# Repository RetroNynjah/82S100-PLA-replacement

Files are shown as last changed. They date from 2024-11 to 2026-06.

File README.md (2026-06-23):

# 82S100 CPLD based PLA replacement
This replacement is a remix of [an old design by Mattis Lind](https://github.com/MattisLind/82S100replacement) based on the ATF1502 and compatible PLDs.  
Revision 1 of the board uses the same pinout so my board can be used with MattisLind's C64 PLA code without modification.
Revision 1b is reverted. The parts are on the back side giving the PLA a cleaner look. Because it's inverted, the pinout of the CPLD is different and it needs different code. Grab code for the right PCB!  

## Code
I have made minor adjustments to Mattis's code to enable the CE pin. The CE pin is grounded in all Commodore machines but this makes the PLA match the original better when tested in chip testers that test the CE pin.
The code is written in CUPL. PLD, JED and SVF files are available in the hdl folder for each board revision.
I have created PLA code for the below models
|Model |Part number |
|:--- |:---  |
|C64 |906114-01 |
|CBM-II HP |906114-05 |
|C16 & Plus/4  |251641-02 |
|CBM 1551 |251641-03 |

## Programming
The CPLD is programmed using JTAG. I'm writing the with svf files using OpenOCD and a FT232H USB breakout board.  
Just be sure to grab the right svf file for your pcb revision.

## Testing
I have custom logic device definitions for Xgpro for the Minipro TL866-II and T48. Those can be used to verify that you have written the correct file and that the PCB is soldered correctly.

## BOM
The part count is low: One ATF1502 CPLD, two 100nF caps (0603) and suitable pin headers.
For rev 1, I prefer flat pins (Arduino stackable headers) or SIL contact strips like [TE 1544210-2](https://www.digikey.se/short/f8hvfqzt) for a number of reason. They give a much lower profile, they stick better to sockets than round machined pins do and they are not as fragile as machined pins. The low profile is ideal for the Plus/4 and the 1551 paddle PLA.  
For rev 1b, machined pins are better as the components are mounted on the back side and the machined headers adds the necessary clearance.  

The CPLD I've been using and recommend is ATF1502ASL-25AU44. It's possible that other varations may work too but it needs to be a 5V part. The 10ns version is causing glitches when used for a C64 PLA.

## Rev 1
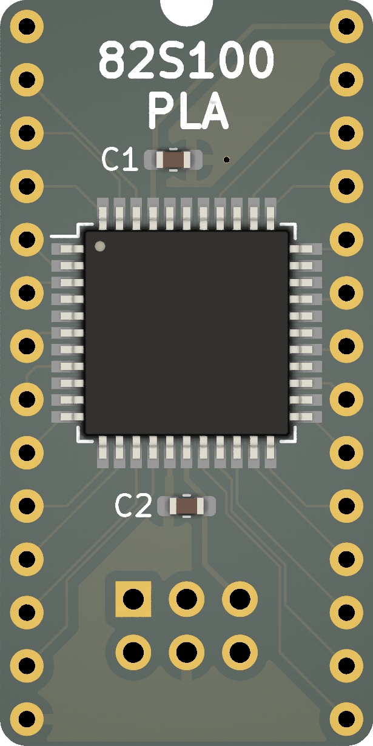
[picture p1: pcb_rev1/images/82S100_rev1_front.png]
Rev 1 front view
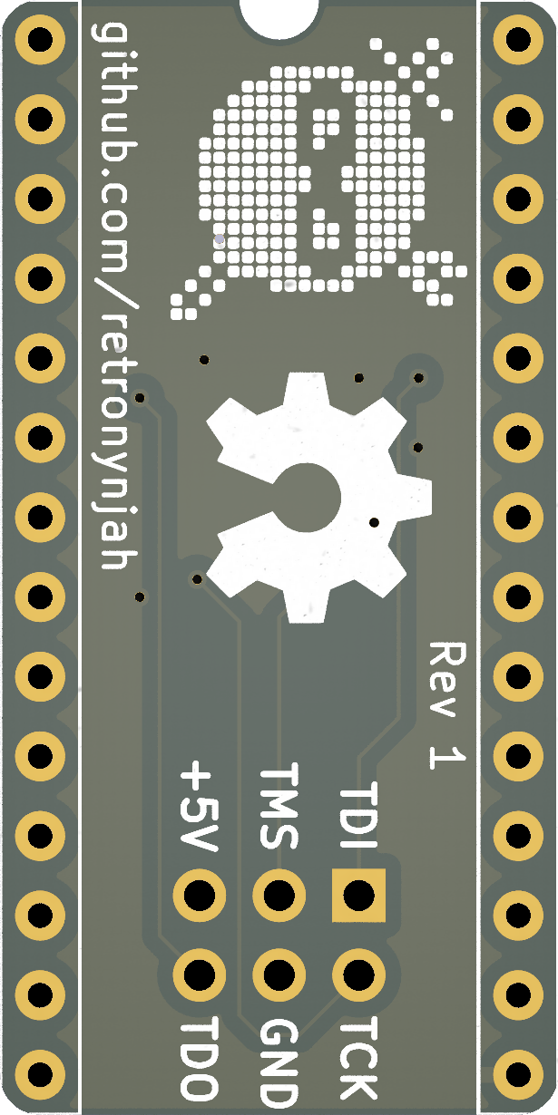
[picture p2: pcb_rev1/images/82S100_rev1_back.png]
Rev 1 back view
    
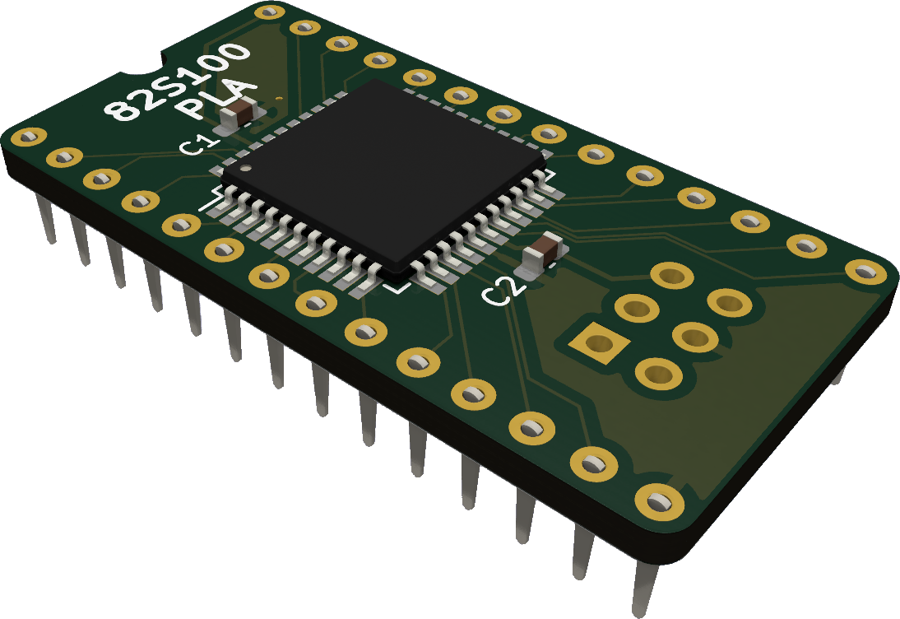
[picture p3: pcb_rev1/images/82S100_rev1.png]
Rev 1b rendered image
  
## Rev 1b
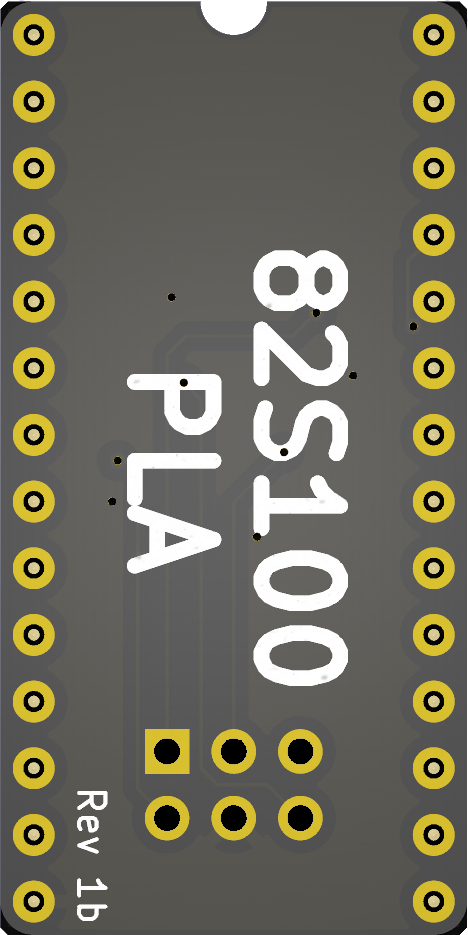
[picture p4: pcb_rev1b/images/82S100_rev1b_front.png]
Rev 1b front view
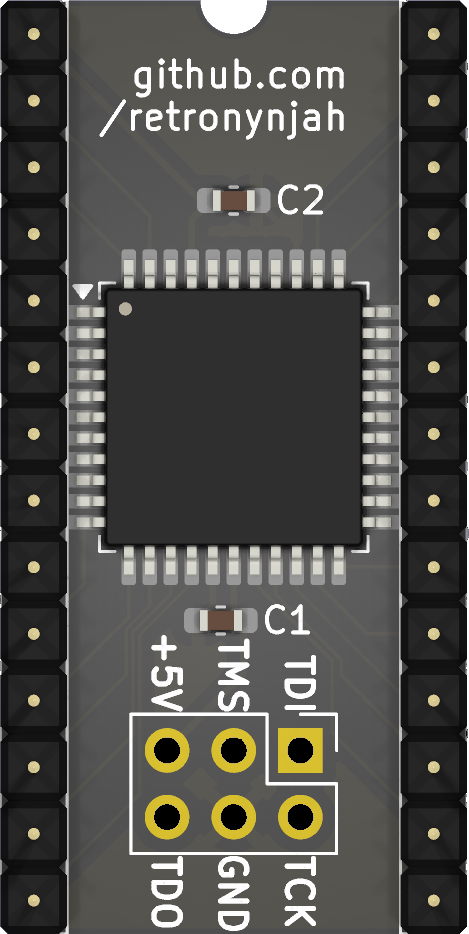
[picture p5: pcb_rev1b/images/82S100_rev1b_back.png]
Rev 1b back view
    
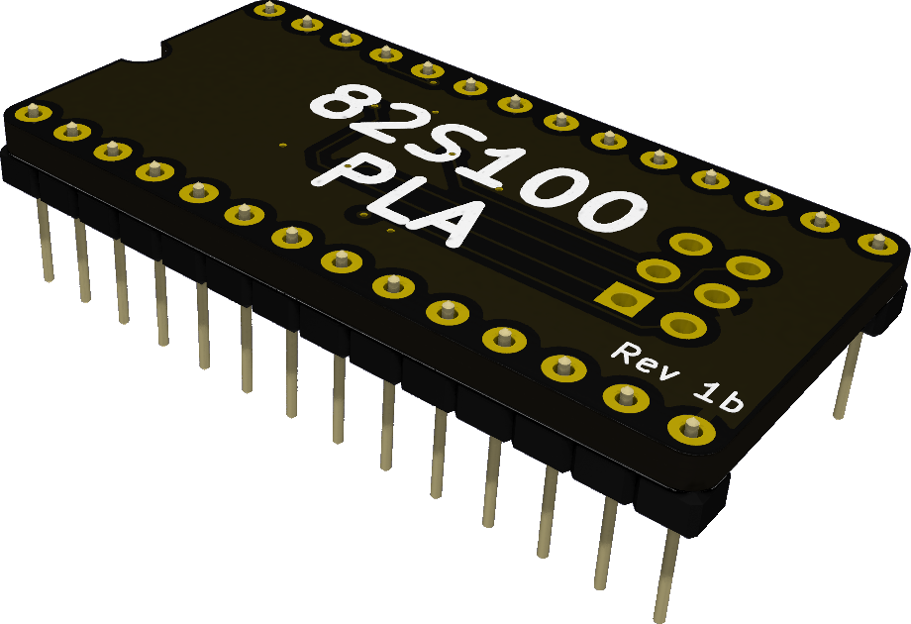
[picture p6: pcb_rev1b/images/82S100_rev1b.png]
Rev 1b rendered image


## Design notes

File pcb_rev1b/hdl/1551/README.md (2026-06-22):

## PLA replacement for Commodore 1551 paddle
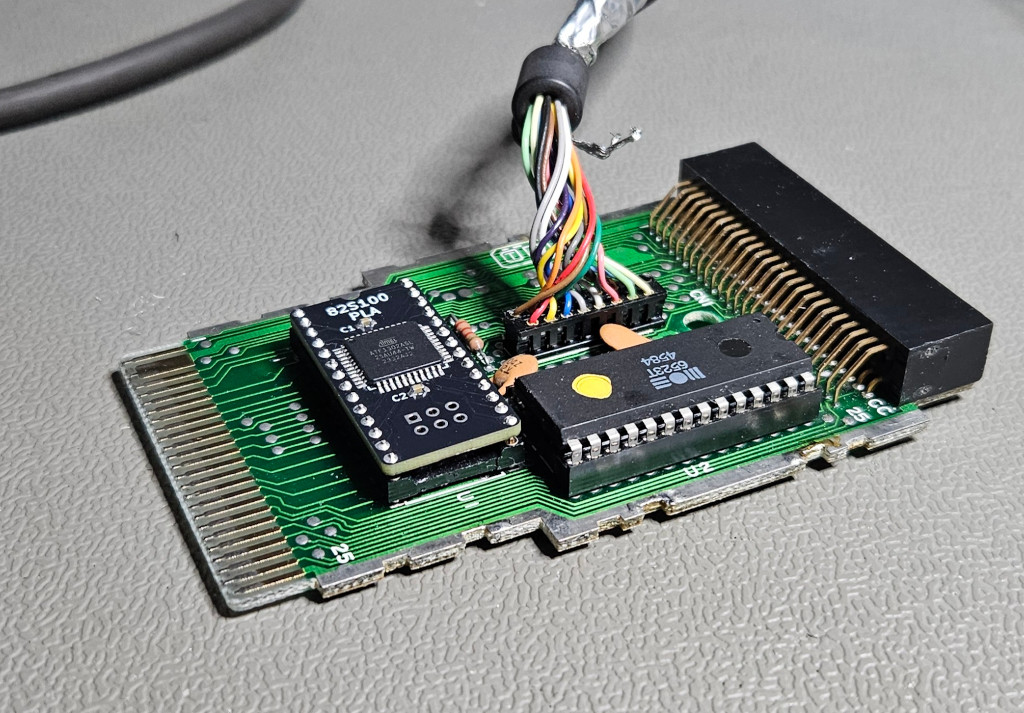
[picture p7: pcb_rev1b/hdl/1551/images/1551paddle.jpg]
Rendered image


This replaces the original MOS part with number 251641-03

F1 isn't connected to anything and isn't needed as far as I can tell but I kept it anyway.
Source code and binaries are in the PLD folder.

I recommend a Rev 1 board with low profile pin headers for the 1551 to make it fit inside the paddle

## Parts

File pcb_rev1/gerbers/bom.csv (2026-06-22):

Designator | Footprint | Quantity | Value | LCSC Part #
C1, C2 | 0603 | 2 | 100n
J1 | DIP-28_W15.24mm_BottomHeadersFlat | 1 | PLA SOCKET
J2 | PinHeader_2x03_P2.54mm_Vertical | 1 | JTAG
U1 | TQFP-44_10x10mm_P0.8mm | 1 | ATF1502

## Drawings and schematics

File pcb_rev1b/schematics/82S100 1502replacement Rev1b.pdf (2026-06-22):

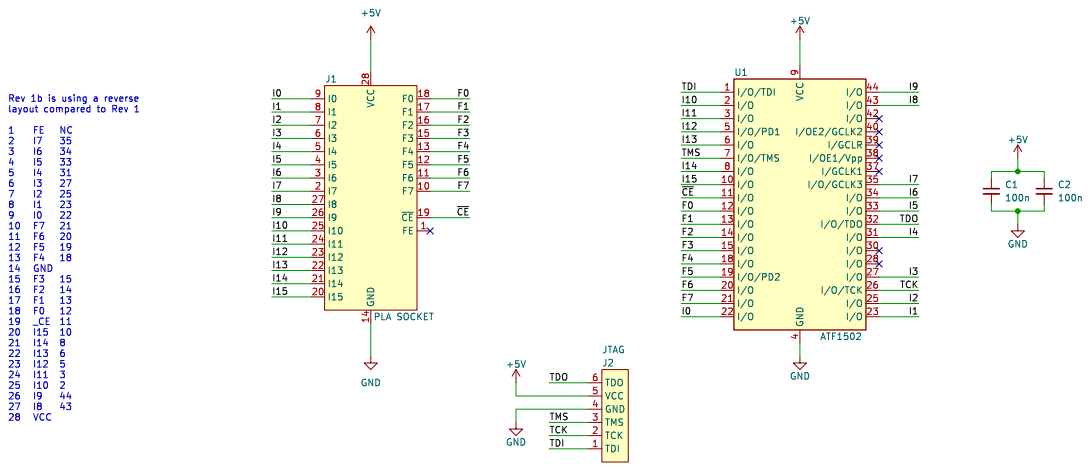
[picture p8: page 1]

I13 F5F3F4F7 Rev 1b is using a reverse

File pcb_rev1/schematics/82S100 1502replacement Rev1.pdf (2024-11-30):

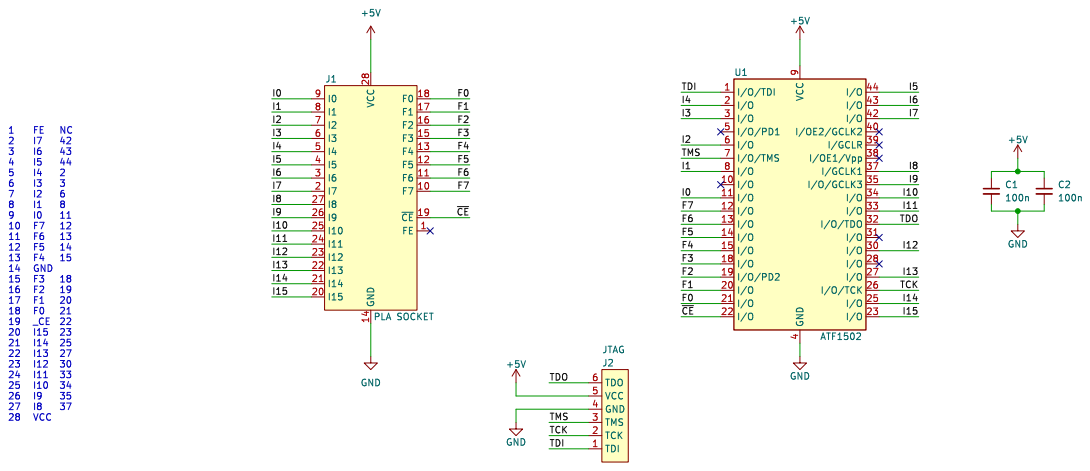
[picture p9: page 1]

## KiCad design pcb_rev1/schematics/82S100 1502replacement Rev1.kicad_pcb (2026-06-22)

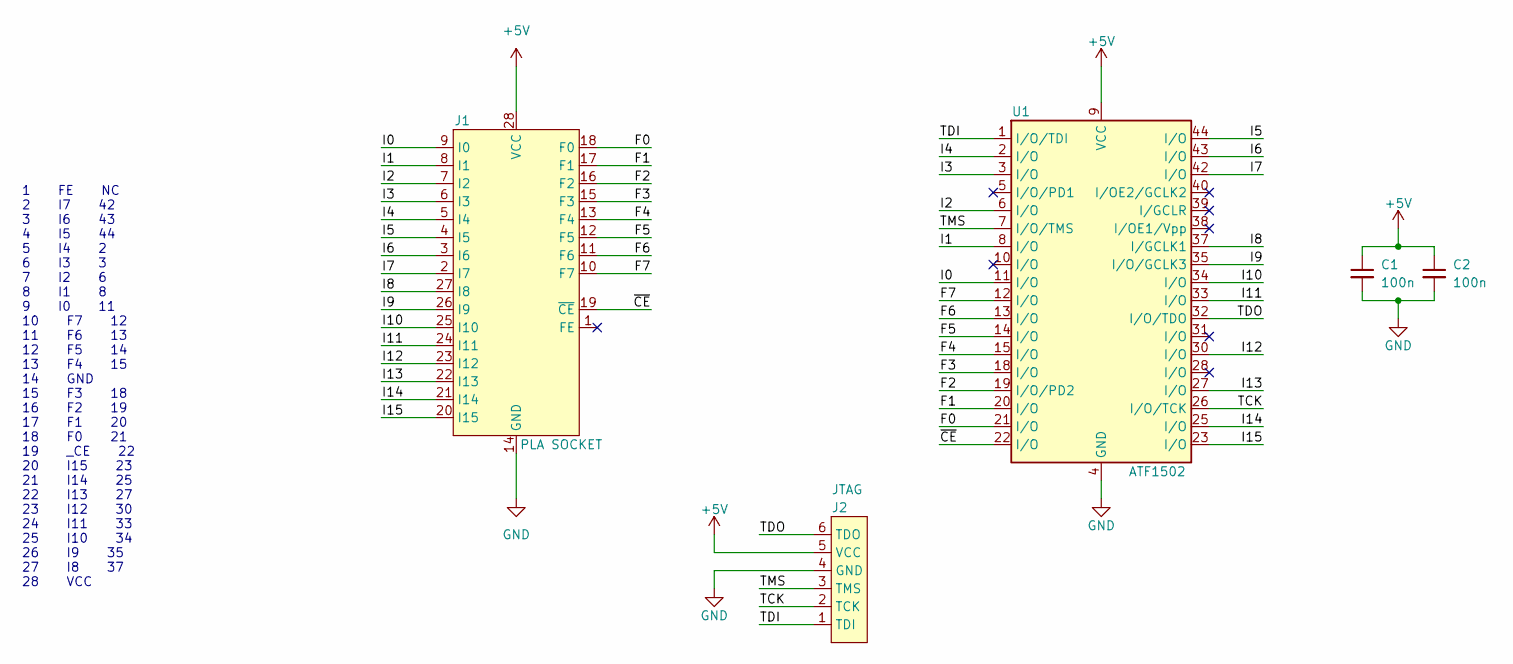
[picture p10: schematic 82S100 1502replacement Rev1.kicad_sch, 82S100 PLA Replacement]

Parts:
C1, C2: 100n; C_0603_1608Metric_Pad1.08x0.95mm_HandSolder
J1: PLA SOCKET; DIP-28_W15.24mm_BottomHeadersFlat
J2: JTAG; PinHeader_2x03_P2.54mm_Vertical
U1: ATF1502; TQFP-44_10x10mm_P0.8mm

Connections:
+5V: C1.1, C2.1, J1.28 (VCC), J2.5 (VCC), U1.9 (VCC), U1.17 (VCC), U1.29 (VCC), U1.41 (VCC)
/F0: J1.18 (F0), U1.21 (I/O)
/F1: J1.17 (F1), U1.20 (I/O)
/F2: J1.16 (F2), U1.19 (I/O/PD2)
/F3: J1.15 (F3), U1.18 (I/O)
/F4: J1.13 (F4), U1.15 (I/O)
/F5: J1.12 (F5), U1.14 (I/O)
/F6: J1.11 (F6), U1.13 (I/O)
/F7: J1.10 (F7), U1.12 (I/O)
/I0: J1.9 (I0), U1.11 (I/O)
/I1: J1.8 (I1), U1.8 (I/O)
/I2: J1.7 (I2), U1.6 (I/O)
/I3: J1.6 (I3), U1.3 (I/O)
/I4: J1.5 (I4), U1.2 (I/O)
/I5: J1.4 (I5), U1.44 (I/O)
/I6: J1.3 (I6), U1.43 (I/O)
/I7: J1.2 (I7), U1.42 (I/O)
/I8: J1.27 (I8), U1.37 (I/GCLK1)
/I9: J1.26 (I9), U1.35 (I/O/GCLK3)
/I10: J1.25 (I10), U1.34 (I/O)
/I11: J1.24 (I11), U1.33 (I/O)
/I12: J1.23 (I12), U1.30 (I/O)
/I13: J1.22 (I13), U1.27 (I/O)
/I14: J1.21 (I14), U1.25 (I/O)
/I15: J1.20 (I15), U1.23 (I/O)
/TCK: J2.2 (TCK), U1.26 (I/O/TCK)
/TDI: J2.1 (TDI), U1.1 (I/O/TDI)
/TDO: J2.6 (TDO), U1.32 (I/O/TDO)
/TMS: J2.3 (TMS), U1.7 (I/O/TMS)
/~CE: J1.19 (~CE), U1.22 (I/O)
GND: C1.2, C2.2, J1.14 (GND), J2.4 (GND), U1.4 (GND), U1.16 (GND), U1.24 (GND), U1.36 (GND)

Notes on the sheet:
1 FE NC 2 I7 42 3 I6 43 4 I5 44 5 I4 2 6 I3 3 7 I2 6 8 I1 8 9 I0 11 10 F7 12 11 F6 13 12 F5 14 13 F4 15 14 GND 15 F3 18 16 F2 19 17 F1 20 18 F0 21 19 _CE 22 20 I15 23 21 I14 25 22 I13 27 23 I12 30 24 I11 33 25 I10 34 26 I9 35 27 I8 37 28 VCC

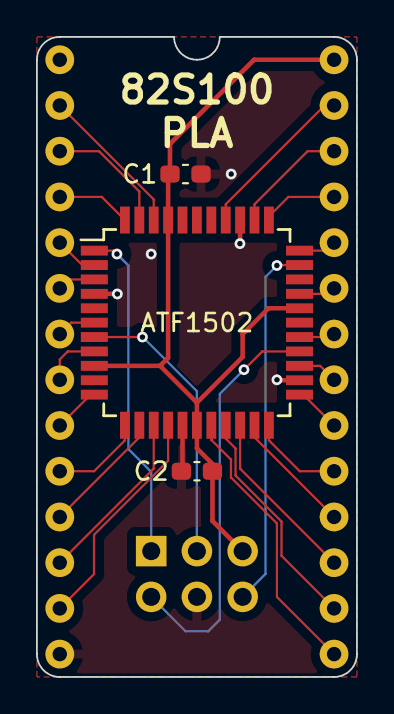
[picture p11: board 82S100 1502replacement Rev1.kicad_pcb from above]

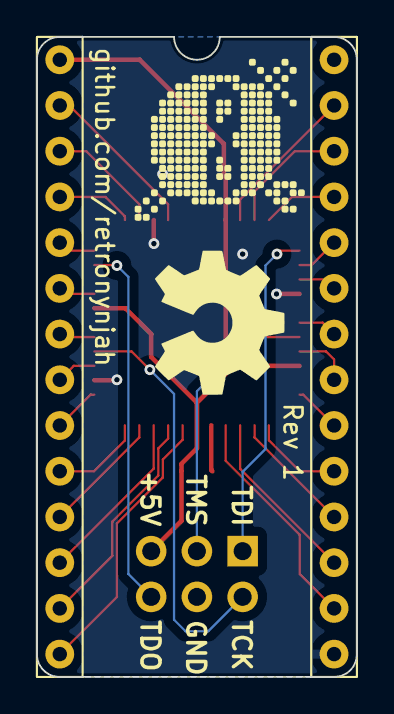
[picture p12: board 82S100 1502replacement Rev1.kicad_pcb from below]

Board: 2 copper layers, 17.8 x 35.6 mm, 7 parts (3 on the bottom side), 31 nets.

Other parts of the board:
Logo: retroninja; LOGO
Logo2: OSHW; LOGO

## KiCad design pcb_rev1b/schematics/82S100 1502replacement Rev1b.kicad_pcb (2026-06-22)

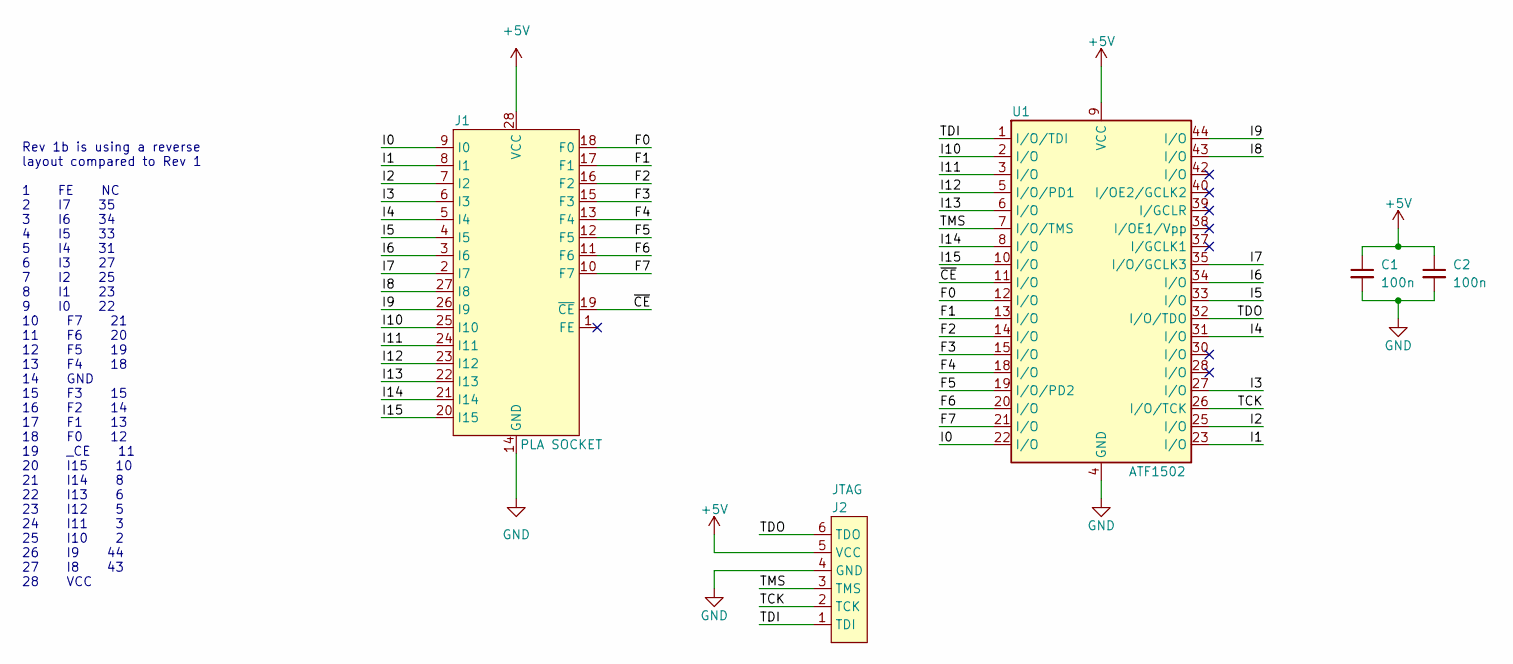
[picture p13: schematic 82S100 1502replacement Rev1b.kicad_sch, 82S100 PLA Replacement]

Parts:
C1, C2: 100n; C_0603_1608Metric_Pad1.08x0.95mm_HandSolder
J1: PLA SOCKET; DIP-28_W15.24mm_BottomHeadersFlat
J2: JTAG; PinHeader_2x03_P2.54mm_Vertical
U1: ATF1502; TQFP-44_10x10mm_P0.8mm

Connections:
+5V: C1.1, C2.1, J1.28 (VCC), J2.5 (VCC), U1.9 (VCC), U1.17 (VCC), U1.29 (VCC), U1.41 (VCC)
/F0: J1.18 (F0), U1.12 (I/O)
/F1: J1.17 (F1), U1.13 (I/O)
/F2: J1.16 (F2), U1.14 (I/O)
/F3: J1.15 (F3), U1.15 (I/O)
/F4: J1.13 (F4), U1.18 (I/O)
/F5: J1.12 (F5), U1.19 (I/O/PD2)
/F6: J1.11 (F6), U1.20 (I/O)
/F7: J1.10 (F7), U1.21 (I/O)
/I0: J1.9 (I0), U1.22 (I/O)
/I1: J1.8 (I1), U1.23 (I/O)
/I2: J1.7 (I2), U1.25 (I/O)
/I3: J1.6 (I3), U1.27 (I/O)
/I4: J1.5 (I4), U1.31 (I/O)
/I5: J1.4 (I5), U1.33 (I/O)
/I6: J1.3 (I6), U1.34 (I/O)
/I7: J1.2 (I7), U1.35 (I/O/GCLK3)
/I8: J1.27 (I8), U1.43 (I/O)
/I9: J1.26 (I9), U1.44 (I/O)
/I10: J1.25 (I10), U1.2 (I/O)
/I11: J1.24 (I11), U1.3 (I/O)
/I12: J1.23 (I12), U1.5 (I/O/PD1)
/I13: J1.22 (I13), U1.6 (I/O)
/I14: J1.21 (I14), U1.8 (I/O)
/I15: J1.20 (I15), U1.10 (I/O)
/TCK: J2.2 (TCK), U1.26 (I/O/TCK)
/TDI: J2.1 (TDI), U1.1 (I/O/TDI)
/TDO: J2.6 (TDO), U1.32 (I/O/TDO)
/TMS: J2.3 (TMS), U1.7 (I/O/TMS)
/~CE: J1.19 (~CE), U1.11 (I/O)
GND: C1.2, C2.2, J1.14 (GND), J2.4 (GND), U1.4 (GND), U1.16 (GND), U1.24 (GND), U1.36 (GND)

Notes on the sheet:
Rev 1b is using a reverse layout compared to Rev 1 1 FE NC 2 I7 35 3 I6 34 4 I5 33 5 I4 31 6 I3 27 7 I2 25 8 I1 23 9 I0 22 10 F7 21 11 F6 20 12 F5 19 13 F4 18 14 GND 15 F3 15 16 F2 14 17 F1 13 18 F0 12 19 _CE 11 20 I15 10 21 I14 8 22 I13 6 23 I12 5 24 I11 3 25 I10 2 26 I9 44 27 I8 43 28 VCC

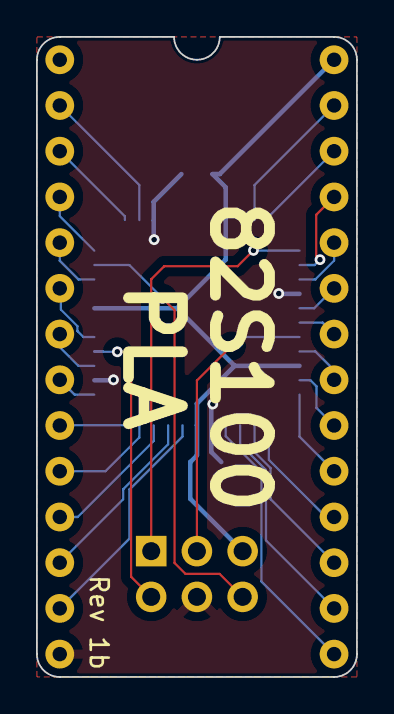
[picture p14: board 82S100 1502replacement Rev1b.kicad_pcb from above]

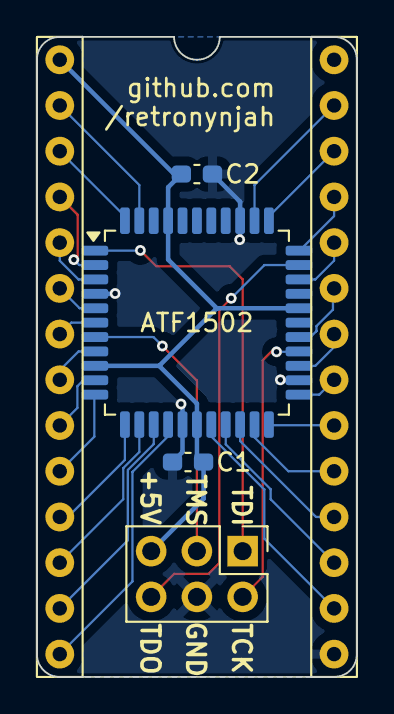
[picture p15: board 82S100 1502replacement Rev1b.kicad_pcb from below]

Board: 2 copper layers, 17.8 x 35.6 mm, 5 parts (4 on the bottom side), 31 nets.

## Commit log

2024-11-30 Initial upload
    PCB rev 1
    [82S100 1502replacement Rev1.kicad_pcb, 82S100 1502replacement Rev1.kicad_sch, equations.ods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]
2026-06-22 Revision 1b
    Added:
    PCB revision 1b,
    906114-05 CBM-II PLA,
    Changed:
    Minor updates to most CUPL code,
    Reorganized file structure,
    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
    [82S100 1502replacement Rev1.kicad_pcb, 82S100 1502replacement Rev1b.kicad_pcb, 82S100 1502replacement Rev1b.kicad_sch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]
2026-06-22 Updated README
    Updated the README to clarify CE pin adjustments and CPLD recommendations. Added testing section for custom logic device definitions.
